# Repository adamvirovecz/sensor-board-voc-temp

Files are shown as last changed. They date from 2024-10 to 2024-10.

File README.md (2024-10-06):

# VOC, Humidity and Temperature Sensor Board
The board includes two sensors from Sensiron:
- **SGP41-D-R4** VOC and NOx sensor,
- **SHT41** temperature and humidity sensor.
The sensor data is accessible via UART interface. The voltage level is 5V, but the input is 3.3V compatible. A TXU0202 level shifter is used.
The sensor board is intended to be used with other Sensiron sensors (like SPS30 and SFA30). The 5V interface was chosen so that a central controller can use the same interface type to connect to any of the sensors.
## Image of the assembled board
TODO
## Repository structure
- bom: interactive bom and csv
- gerbers: manufacturing files
- pdf: pdf output of schematic

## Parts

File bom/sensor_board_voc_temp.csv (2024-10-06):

Reference | Value | Manufacturer | MPN | Datasheet | Footprint | Qty | DNP
C1 | 10 µF | KYOCERA AVX | 0805YC106KAT2A | ~ | Capacitor_SMD:C_0805_2012Metric | 1
C2,C6,C7,C8 | 1 µF | TDK | C1608X7R1C105K080AC | ~ | Capacitor_SMD:C_0603_1608Metric | 4
C3,C10 | 4.7 µF | Murata | GRM21BR71C475KE51K | ~ | Capacitor_SMD:C_0805_2012Metric | 2
C4,C5,C9 | 100 nF | KYOCERA AVX | 0603YC104KAT2A | ~ | Capacitor_SMD:C_0603_1608Metric | 3
D1 | SMAJ5.0A | Littelfuse | SMAJ5.0A | https://www.littelfuse.com/media?itemid=75e32973-b177-4ee3-a0ff-cedaf1abdb93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 | Diode_SMD:D_SMA | 1
D2,D3 | ESD5Z5.0T5G | onsemi | ESD5Z5.0T5G | https://hu.mouser.com/datasheet/2/308/1/ESD5Z2_5T1_D-2311718.pdf | Diode_SMD:D_SOD-523 | 2
D4 | 150060VS75000 | Wurth Elektronik | 150060VS75000 | https://www.we-online.com/components/products/datasheet/150060VS75000.pdf | LED_SMD:LED_0603_1608Metric | 1
D5 | ESDALC6V1W5 | STMicroelectronics | ESDALC6V1W5 | https://www.st.com/resource/en/datasheet/esdalc6v1w.pdf | Package_TO_SOT_SMD:SOT-353_SC-70-5 | 1
F1 | 0.35A PPTC | Littelfuse | nanoSMDC035F-2 | ~ | Fuse_Littelfuse:Fuse_LittelFuse_nanoSMDC_Series | 1
J1 | Main_Connector | Molex | 213226-0410 | ~ | Connector_Molex_CLIK-Mate:Molex_CLIK_Mate_213226_0410_1x04_1MP_P1.50mm_Horizontal | 1
R1,R2,R3,R4 | 10 Ω | Vishay | CRCW060310R0FKEAHP | ~ | Resistor_SMD:R_0603_1608Metric | 4
R5 | 4.7 Ω | Vishay | CRCW06034R70FKEA | ~ | Resistor_SMD:R_0603_1608Metric | 1
R6,R7 | 10k | Vishay | CRCW060310K0FKECC | ~ | Resistor_SMD:R_0603_1608Metric | 2
R8 | 680 Ω | Vishay | CRCW0603680RFKEA | ~ | Resistor_SMD:R_0603_1608Metric | 1
U1 | TPS7A2033PDBVR | Texas Instruments | TPS7A2033PDBVR | https://www.ti.com/lit/ds/symlink/tps7a20.pdf | Package_TO_SOT_SMD:SOT-23-5 | 1
U2 | TXU0202DCUR | Texas Instruments | TXU0202DCUR | https://www.ti.com/lit/ds/symlink/txu0202.pdf | Package_SO:VSSOP-8_2.3x2mm_P0.5mm | 1
U3 | SGP41-D-R4 | Sensirion | SGP41-D-R4 | https://www.sensirion.com/media/documents/5FE8673C/61E96F50/Sensirion_Gas_Sensors_Datasheet_SGP41.pdf | Package_DFN_QFN_Custom:DFN-6-1EP_2.44x2.44mm_P0.8mm_EP1.25x1.64mm | 1
U4 | STM32G030J6Mx | STMicroelectronics | STM32G030J6M6 | https://www.st.com/resource/en/datasheet/stm32g030j6.pdf | Package_SO:SOIC-8_3.9x4.9mm_P1.27mm | 1
U5 | SHT4x | Sensirion | SHT41-AD1F-R2 | https://sensirion.com/media/documents/33FD6951/624C4357/Datasheet_SHT4x.pdf | Sensor_Humidity:Sensirion_DFN-4_1.5x1.5mm_P0.8mm_SHT4x_NoCentralPad | 1

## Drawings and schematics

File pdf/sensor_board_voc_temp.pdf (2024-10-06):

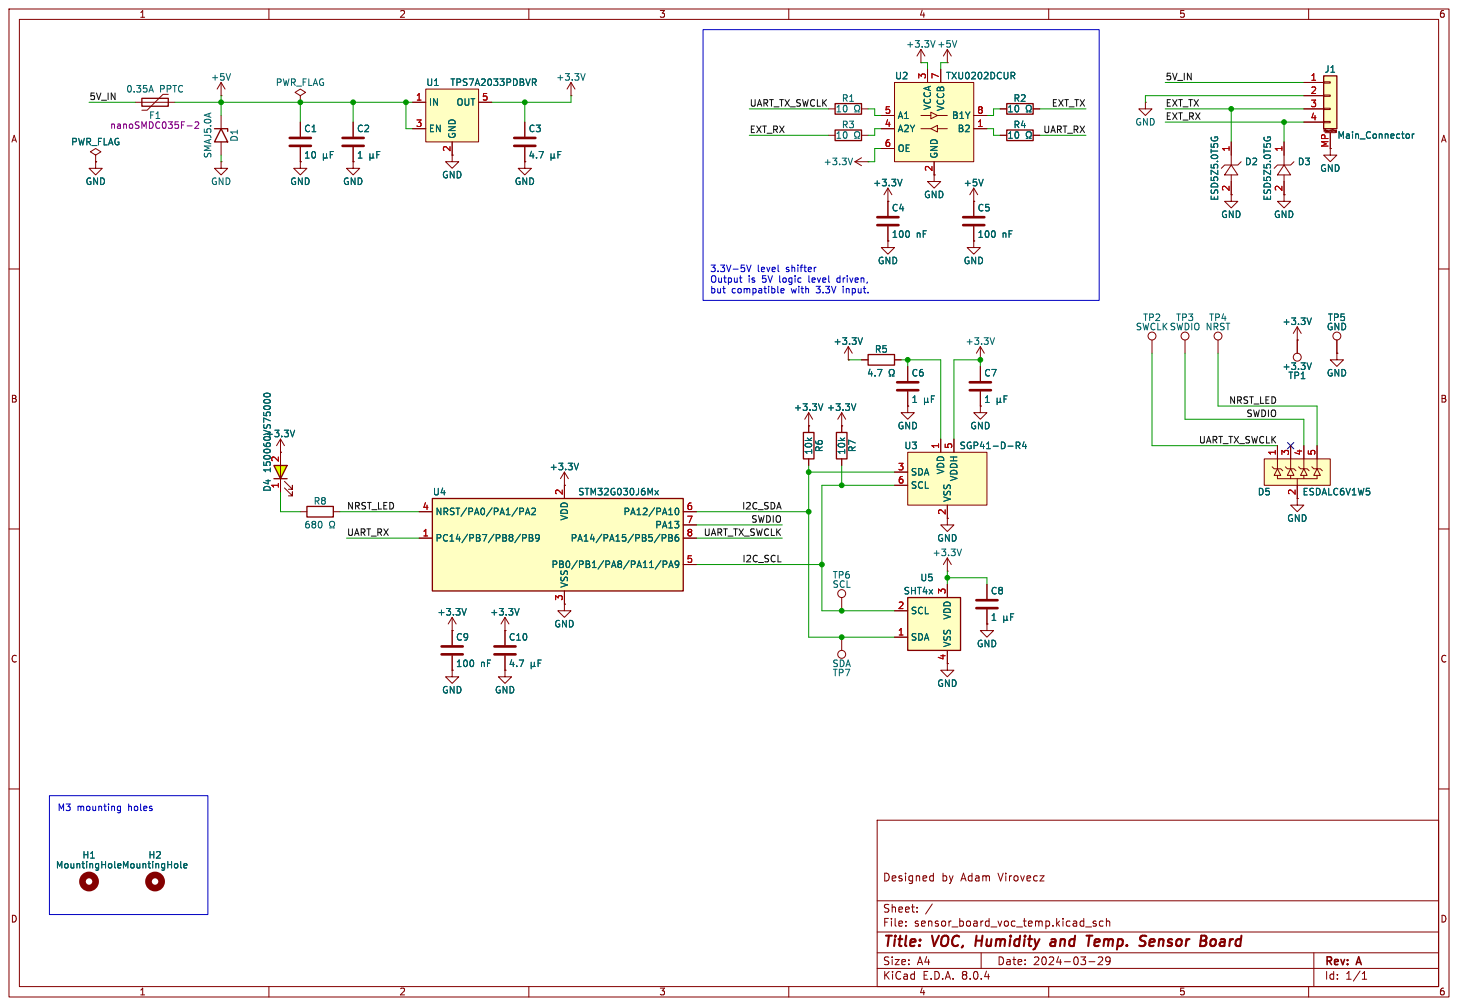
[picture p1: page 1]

Id: 1/1 Title: VOC, Humidity and Temp. Sensor Board

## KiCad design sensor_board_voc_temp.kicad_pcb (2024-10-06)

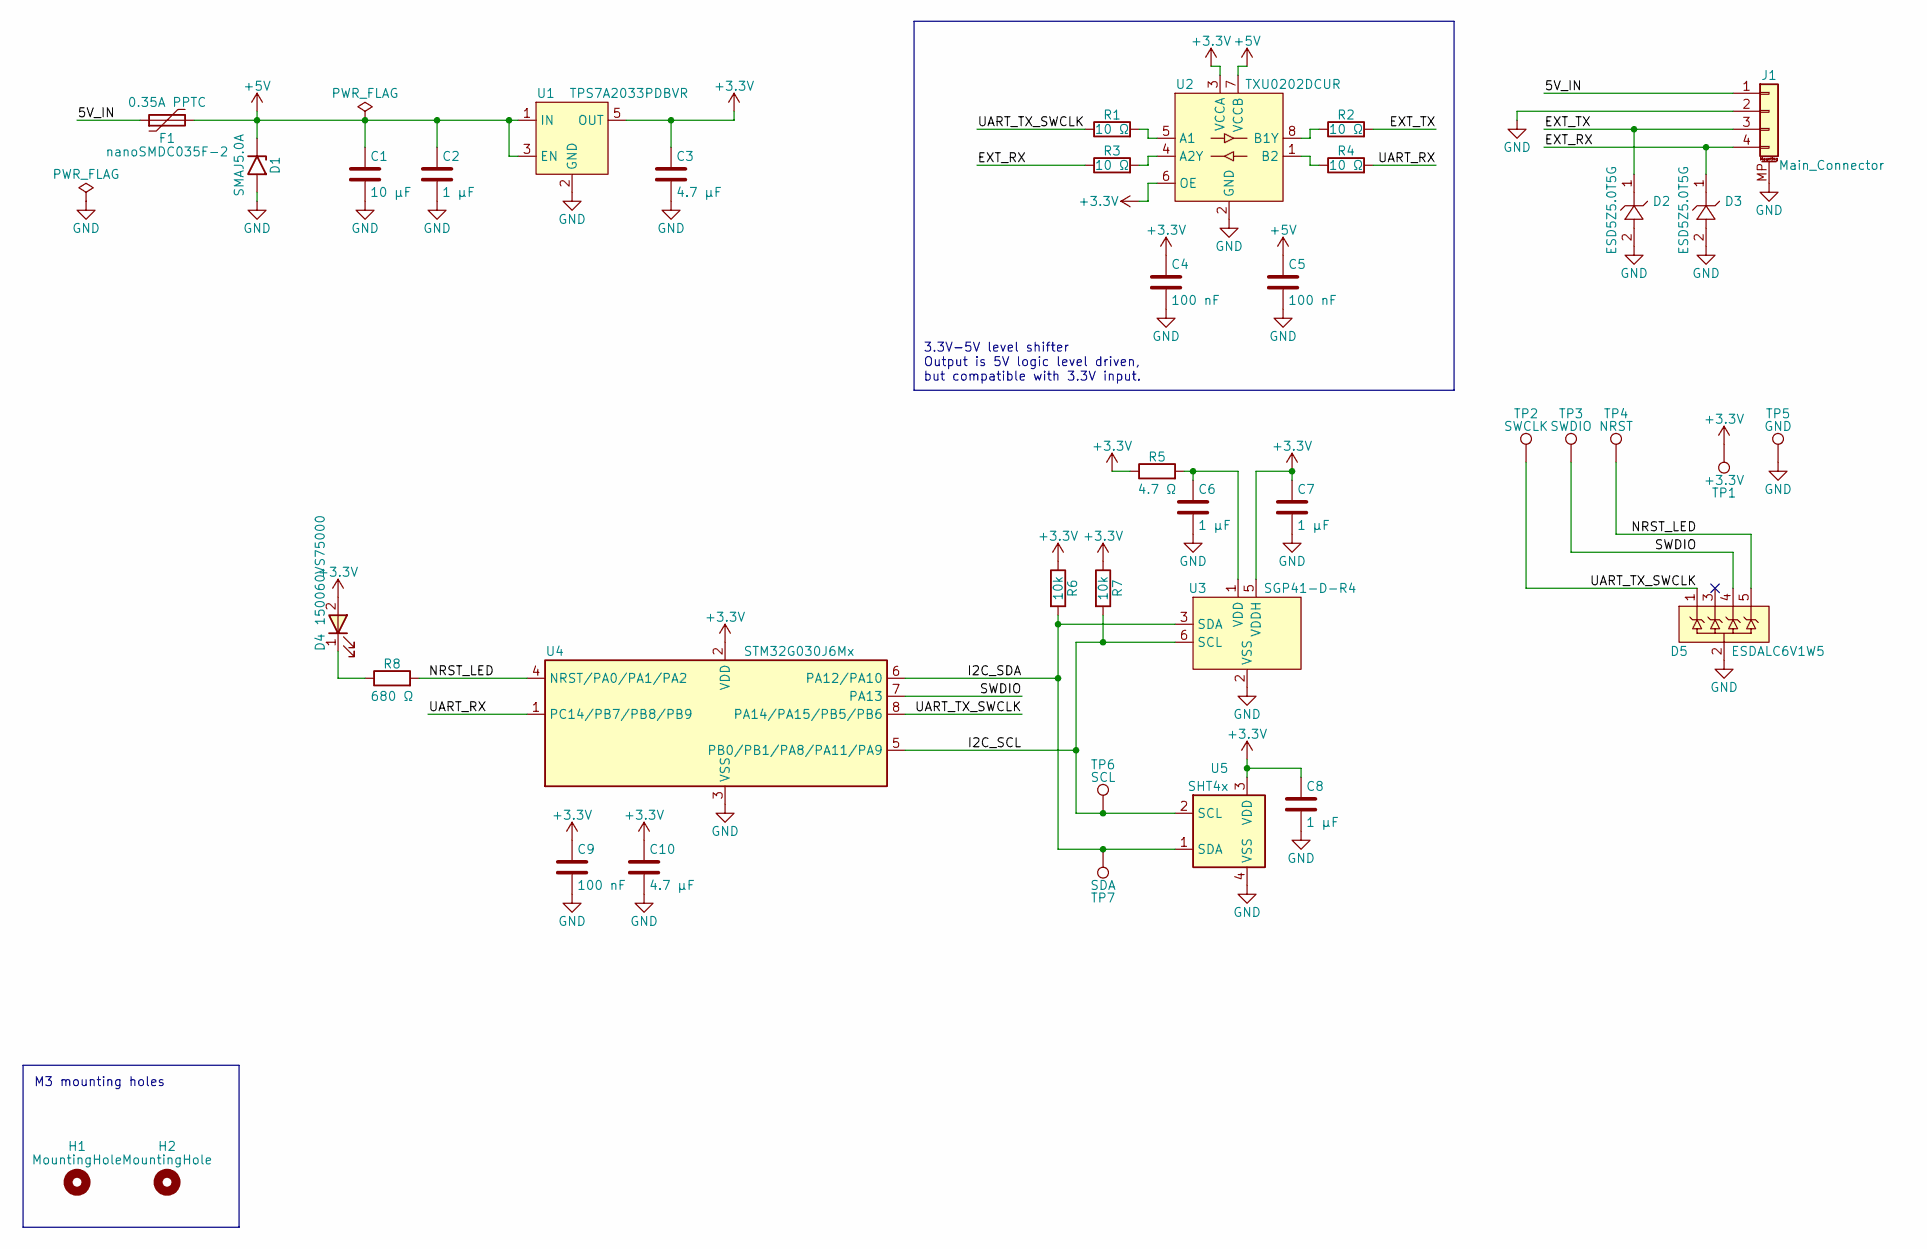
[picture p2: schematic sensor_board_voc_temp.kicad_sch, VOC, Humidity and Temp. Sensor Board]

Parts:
C1: 10 µF; C_0805_2012Metric; MPN 0805YC106KAT2A
C2, C6, C7, C8: 1 µF; C_0603_1608Metric; MPN C1608X7R1C105K080AC
C3, C10: 4.7 µF; C_0805_2012Metric; MPN GRM21BR71C475KE51K
C4, C5, C9: 100 nF; C_0603_1608Metric; MPN 0603YC104KAT2A
D1: SMAJ5.0A; D_SMA; MPN SMAJ5.0A
D2, D3: ESD5Z5.0T5G; D_SOD-523; MPN ESD5Z5.0T5G
D4: 150060VS75000; LED_0603_1608Metric; MPN 150060VS75000
D5: ESDALC6V1W5; SOT-353_SC-70-5; MPN ESDALC6V1W5
F1: 0.35A PPTC; Fuse_LittelFuse_nanoSMDC_Series; MPN nanoSMDC035F-2
H1, H2: MountingHole; MountingHole_3.2mm_M3_ISO7380
J1: Main_Connector; Molex_CLIK_Mate_213226_0410_1x04_1MP_P1.50mm_Horizontal; MPN 213226-0410
R1, R2, R3, R4: 10 Ω; R_0603_1608Metric; MPN CRCW060310R0FKEAHP
R5: 4.7 Ω; R_0603_1608Metric; MPN CRCW06034R70FKEA
R6, R7: 10k; R_0603_1608Metric; MPN CRCW060310K0FKECC
R8: 680 Ω; R_0603_1608Metric; MPN CRCW0603680RFKEA
TP1: +3.3V; TestPoint_Pad_D1.5mm
TP2: SWCLK; TestPoint_Pad_D1.5mm
TP3: SWDIO; TestPoint_Pad_D1.5mm
TP4: NRST; TestPoint_Pad_D1.5mm
TP5: GND; TestPoint_Pad_D1.5mm
TP6: SCL; TestPoint_Pad_D1.5mm
TP7: SDA; TestPoint_Pad_D1.5mm
U1: TPS7A2033PDBVR; SOT-23-5; MPN TPS7A2033PDBVR
U2: TXU0202DCUR; VSSOP-8_2.3x2mm_P0.5mm; MPN TXU0202DCUR
U3: SGP41-D-R4; DFN-6-1EP_2.44x2.44mm_P0.8mm_EP1.25x1.64mm; MPN SGP41-D-R4
U4: STM32G030J6Mx; SOIC-8_3.9x4.9mm_P1.27mm; MPN STM32G030J6M6
U5: SHT4x; Sensirion_DFN-4_1.5x1.5mm_P0.8mm_SHT4x_NoCentralPad; MPN SHT41-AD1F-R2

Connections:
+3.3V: C3.1, C4.1, C7.1, C8.1, C9.1, C10.1, D4.2 (A), R5.1, R6.1, R7.1, TP1.1, U1.5 (OUT), U2.3 (VCCA), U2.6 (OE), U3.5 (VDDH), U4.2 (VDD), U5.3 (VDD)
+5V: C1.1, C2.1, C5.1, D1.1 (A1), F1.2, U1.1 (IN), U1.3 (EN), U2.7 (VCCB)
/5V_IN: F1.1, J1.1
/EXT_RX: D3.1, J1.4, R3.1
/EXT_TX: D2.1, J1.3, R2.2
/I2C_SCL: R7.2, TP6.1, U3.6 (SCL), U4.5 (PB0/PB1/PA8/PA11/PA9), U5.2 (SCL)
/I2C_SDA: R6.2, TP7.1, U3.3 (SDA), U4.6 (PA12/PA10), U5.1 (SDA)
/NRST_LED: D5.5, R8.2, TP4.1, U4.4 (NRST/PA0/PA1/PA2)
/SWDIO: D5.4, TP3.1, U4.7 (PA13)
/UART_RX: R4.2, U4.1 (PC14/PB7/PB8/PB9)
/UART_TX_SWCLK: D5.1, R1.1, TP2.1, U4.8 (PA14/PA15/PB5/PB6)
GND: C1.2, C2.2, C3.2, C4.2, C5.2, C6.2, C7.2, C8.2, C9.2, C10.2, D1.2 (A2), D2.2, D3.2, D5.2, J1.2, J1.MP (MountPin), TP5.1, U1.2 (GND), U2.2 (GND), U3.2 (VSS), U3.4 (N/A), U3.EP, U4.3 (VSS), U5.4 (VSS)
unnamed: D4.1 (K), R8.1
unnamed: R1.2, U2.5 (A1)
unnamed: R3.2, U2.4 (A2Y)
unnamed: R2.1, U2.8 (B1Y)
unnamed: R4.1, U2.1 (B2)
unnamed: C6.1, R5.2, U3.1 (VDD)

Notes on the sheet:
M3 mounting holes
3.3V-5V level shifter Output is 5V logic level driven, but compatible with 3.3V input.

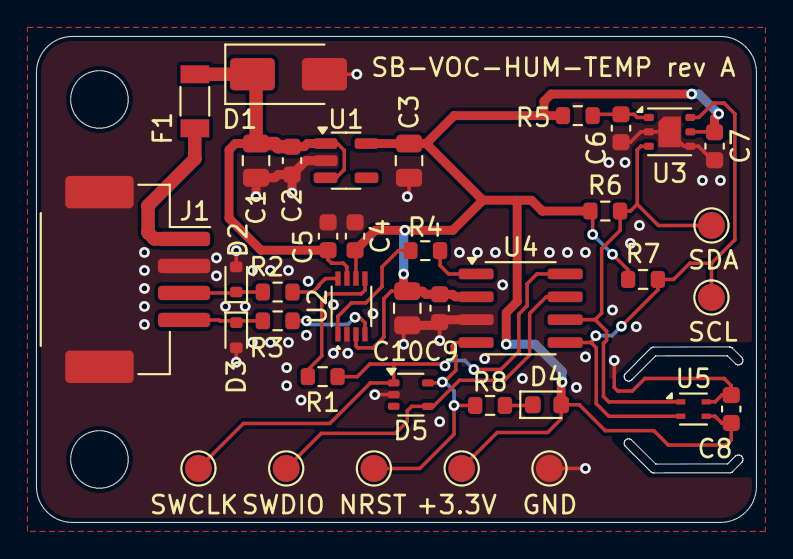
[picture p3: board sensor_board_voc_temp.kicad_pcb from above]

Board: 2 copper layers, 40.0 x 27.0 mm, 39 parts (0 on the bottom side), 18 nets.
